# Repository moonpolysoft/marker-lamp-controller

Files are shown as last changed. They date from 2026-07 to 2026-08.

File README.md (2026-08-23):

# F-150 Lightning Auxiliary Marker-Lamp Controller

An open-hardware controller that makes aftermarket amber grille marker lamps
follow the factory parking lamps on a 2023 Ford F-150 Lightning—without using
the CAN bus or trailer-lighting outputs.

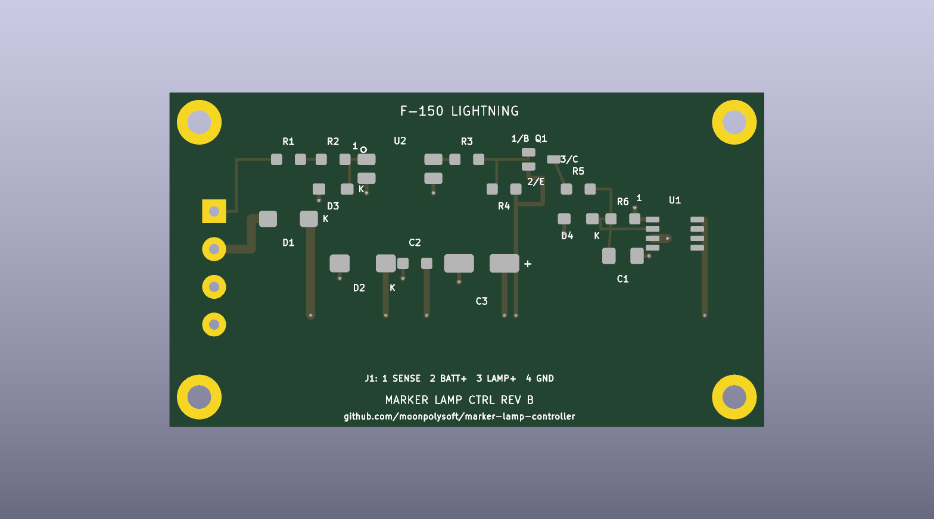
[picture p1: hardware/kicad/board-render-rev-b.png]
Revision B controller PCB


## Status

- Revision A was assembled, bench tested, and verified in the vehicle.
- The selected driver-side rear parking-lamp signal provides the desired lamp
  behavior. No front-lamp or CAN connection is required.
- Revision B corrects the three assembly issues found on Revision A. A
  Revision B board has been assembled, bench tested, installed, and verified
  working in the vehicle.
- The current enclosure prototype has been printed and its mechanical fit is
  confirmed, including the revised connector opening, boss clearances, and
  recessed lid screws.

This remains a hobbyist engineering prototype, not a Ford-approved accessory
or a safety-certified automotive product. Read [Safety](#safety) before
building or installing it.

## Finished build

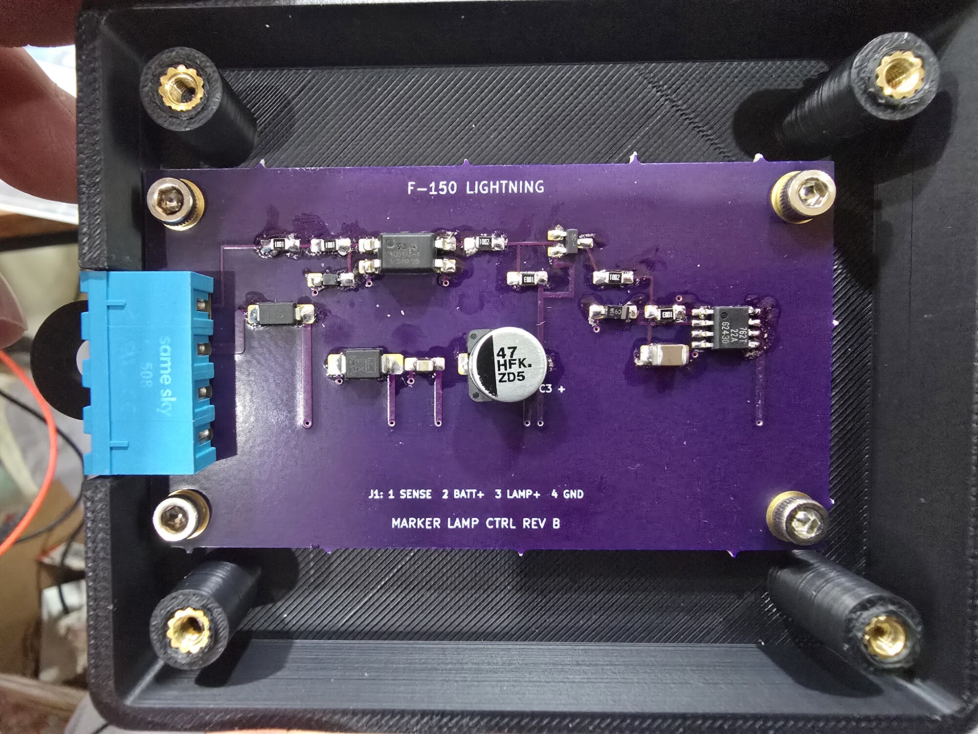
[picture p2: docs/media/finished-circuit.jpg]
Assembled Revision B controller installed in the printed enclosure


The completed controller follows the selected factory parking-lamp signal and
switches the three aftermarket amber grille lamps as intended.

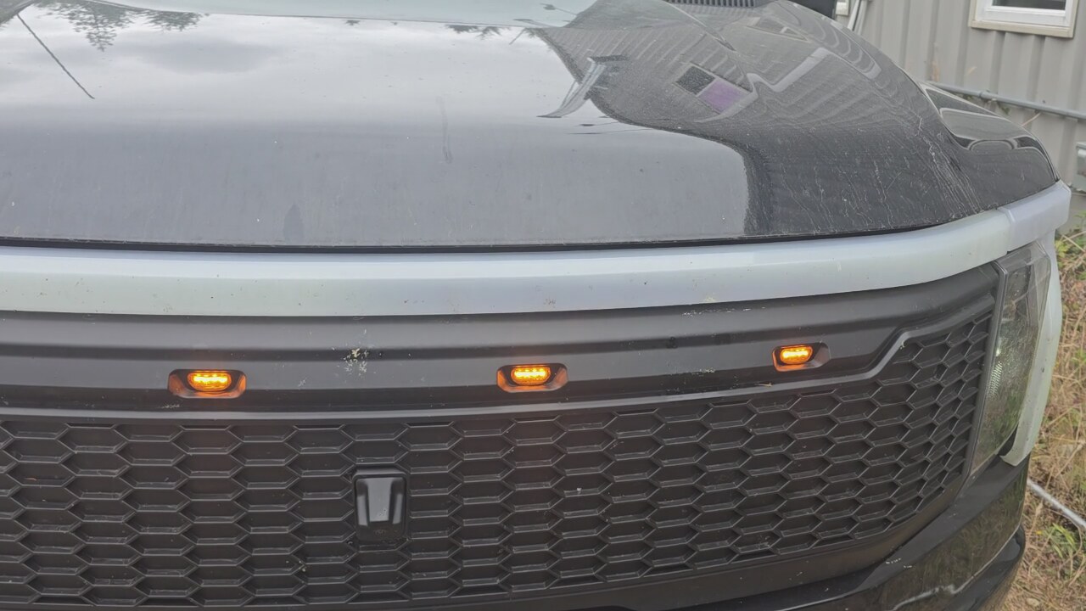
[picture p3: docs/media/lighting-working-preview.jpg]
Video preview showing the auxiliary amber grille lamps illuminated


[Play or download the installation demonstration (MP4, H.264/AAC)](docs/media/lighting-working.mp4)

## What it does

The controller senses the factory rear parking-lamp output through an
optocoupler and drives the aftermarket LEDs from a separate fused 12 V supply
using a protected high-side switch. The factory lamp circuit supplies only the
sense current; it does not power the added lamps.

```text
Factory rear parking-lamp output ── isolated sense/filter ──┐
                                                            │
Fused 12 V supply ── protected high-side switch ── marker lamps
Vehicle ground ─────────────────────────────────── marker return
```

The tested aftermarket lamp assembly draws approximately 0.25 A with the
vehicle low-voltage system energized. The observed sense signal reads roughly
6 V with the truck off and 8 V with it on when measured by a multimeter,
consistent with a pulse-width-modulated automotive lamp output.

## Repository contents

| Path | Contents |
|---|---|
| [`hardware/kicad/`](hardware/kicad/) | KiCad boards, deterministic PCB generator, BOM, DRC reports, Gerbers, drill files, and OSH Park upload archives |
| [`hardware/controller-design.md`](hardware/controller-design.md) | Circuit architecture, component rationale, and validation notes |
| [`enclosure/`](enclosure/) | Parametric OpenSCAD enclosure source and printable STL exports |
| [`docs/rear-parking-wire-test.md`](docs/rear-parking-wire-test.md) | Procedure used to identify and verify the vehicle signal |
| [`docs/media/`](docs/media/) | Finished controller photo and in-vehicle demonstration video |

Revision B is the current PCB. Revision A files remain available as design
history but include known assembly defects; do not order Revision A.

## Building the board

The easiest fabrication input is:

[`hardware/kicad/fabrication-rev-b/marker-lamp-controller-rev-b-oshpark.zip`](hardware/kicad/fabrication-rev-b/marker-lamp-controller-rev-b-oshpark.zip)

The board is a two-layer, 80 × 45 mm design made for OSH Park's standard
two-layer service. Review the current [`BOM.csv`](hardware/kicad/BOM.csv),
because distributor stock and manufacturer lifecycle status change over time.
Connector pinout, board specifications, regeneration instructions, and known
Revision A defects are documented in the
[`hardware/kicad/README.md`](hardware/kicad/README.md).

To regenerate the PCB source with KiCad 10's Python environment:

```sh
python3 hardware/kicad/generate_pcb.py
```

The generator and
[`circuit-netlist.md`](hardware/kicad/circuit-netlist.md) are the authoritative
circuit sources. This project currently does not contain a conventional KiCad
schematic.

## Printing the enclosure

Open [`controller_enclosure.scad`](enclosure/controller_enclosure.scad) in
OpenSCAD and select `base` or `lid`, or print the supplied STL files. See the
[`enclosure/README.md`](enclosure/README.md) for hardware dimensions, material
recommendations, and print settings. The lid should be printed with a 5 mm
brim.

## Installation summary

J1 uses a Same Sky `TBP01R1-508-04BE` board header with a
`TBP01P1-508-04BE` wire-side plug:

| Pin | Signal | Connection |
|---:|---|---|
| 1 | `SENSE` | Verified parking-lamp signal tap |
| 2 | `BATT+` | Separately fused 12 V supply |
| 3 | `LAMP+` | Switched positive output to marker LEDs |
| 4 | `GND` | Chassis ground and lamp return |

Place the branch fuse near the power source. The design documentation calls
for a 2 A fuse and 18 AWG automotive primary wire for the tested 0.25 A load.
Confirm wiring, fuse size, polarity, and connector numbering against your own
vehicle and hardware; model-year and trim wiring can differ.

## Safety

Automotive electrical systems can produce load-dump, inductive, reverse-
polarity, and electrostatic transients. A wiring fault can damage vehicle
modules or start a fire. Disconnect the low-voltage battery as directed by the
vehicle service procedure before permanent wiring, protect added conductors
with an appropriately placed fuse, use automotive-rated wire and abrasion
protection, and secure the assembly away from heat, water, sharp edges, and
moving parts.

Do not treat a zero-error DRC result as validation of electrical safety. Test
every assembled board with a current-limited bench supply before vehicle use.
You build and install this project at your own risk.

Ford and F-150 Lightning are trademarks of their respective owner. This
project is independent and is not affiliated with or endorsed by Ford Motor
Company.

## Contributing

Bug reports, measurements, documentation corrections, and design improvements
are welcome. See [`CONTRIBUTING.md`](CONTRIBUTING.md) before submitting a
change. In particular, identify the PCB revision and vehicle model year/trim
when reporting electrical behavior.

## License

This project is open hardware licensed under the
[CERN Open Hardware Licence Version 2—Strongly Reciprocal](LICENSE), SPDX
identifier `CERN-OHL-S-2.0`.

You may use, study, modify, manufacture, and distribute the design subject to
the licence terms. The strongly reciprocal variant was selected so that
distributed modified designs and products remain accompanied by corresponding
design source. The licence includes warranty and liability disclaimers; it is
not a certification of fitness for automotive use.

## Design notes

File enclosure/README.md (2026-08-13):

# Controller Enclosure Concept

`controller_enclosure.scad` is a parametric enclosure consisting of a base and
lid sized for the current Revision B controller PCB. Its fit has been confirmed
with a printed prototype.

Default external dimensions are approximately 96 × 80 × 23.2 mm, excluding
mounting tabs. The lid roof is 4.2 mm thick so recessed screw heads retain a
1.2 mm supporting floor.

The left wall has a support-free, top-open notch sized to admit the Same Sky
`TBP01P1-508-04BE` four-position mating plug from outside. The lid lip is
relieved over the same opening. The nominal 22.5 mm opening width provides
approximately 2.2 mm total clearance around the plug's 20.32 mm length.

The PCB is shifted toward the J1 wall, leaving 0.5 mm nominal clearance
between that PCB edge and the inside wall. The wider enclosure provides more
than 2 mm nominal radial clearance between the populated PCB corners and the
nearest lid bosses. The lid bosses are also inset far enough to leave 1.6 mm
nominal clearance from the inside edge of the lid lip.

The base notch and lid relief deliberately use mirrored source coordinates:
the lid is printed exterior-face down and flipped for assembly. This makes the
two openings align when the enclosure is closed.

Revision B moves J1 by 7 mm along the PCB edge to clear its mounting hole.
The enclosure opening center follows the new connector position.

The base is 19 mm tall, including its 3 mm floor. The solid wall beneath the
J1 notch is 9.5 mm tall.

## Generate models

Open the file in OpenSCAD and change `part`:

```scad
part = "base";
part = "lid";
part = "assembly";
```

Export the base and lid separately as STL.

Command-line examples:

```sh
openscad -D 'part="base"' -o controller_base.stl controller_enclosure.scad
openscad -D 'part="lid"' -o controller_lid.stl controller_enclosure.scad
```

## Printing assumptions

- Material: ASA preferred for heat and UV resistance; PETG is suitable for
  an interior dry prototype. PLA is not recommended in a vehicle.
- Layer height: 0.20 mm
- Walls: at least 4 perimeters
- Top/bottom layers: at least 5
- Infill: 30% or greater around mounting tabs
- Print both pieces with their large flat exterior faces on the build plate.
- Lid: use a 5 mm brim to prevent the edges from peeling up from the print
  bed.

## Hardware assumptions

- Lid: four M3 machine screws into heat-set inserts.
- Lid screw recesses: 5.8 mm diameter × 3.0 mm deep, sized for nominal
  5.5 mm-diameter, 3.0 mm-tall heads. Verify the actual screw heads before
  the final print.
- Insert pocket: 4.2 mm diameter × 5.5 mm deep; adjust these two parameters to
  the actual insert manufacturer's recommended hole dimensions.
- Lid insert bosses finish 0.75 mm below the base rim to keep heat-set-insert
  squeeze-out from interfering with lid fit.
- PCB: four M3 screws driven into 2.7 mm pilot holes in printed standoffs.
- PCB mounting pattern: 72 × 37 mm.
- The two PCB standoffs opposite J1 include a 0.5 mm outward print-fit
  adjustment, producing 72.5 mm modeled spacing in that axis.
- No environmental gasket is required for the dry installation location; the
  existing shallow channel may be left unused.

The current lid uses screws, not printed snap fits. The model includes an
O-ring/gasket channel concept, but sealing has not been validated. Use sealed
cable glands or sealed bulkhead connectors for an exterior/underbody mounting
location.

## Checks before vehicle installation

- Confirm the selected heat-set insert diameter and length before printing.
- Confirm that the installed lid screws remain long enough for full insert
  engagement with the recessed 4.2 mm lid roof.
- Verify that the populated PCB, Q1 rework, C3, header, and mating plug clear
  the lid and screw bosses.
- Verify that the connector can be inserted and removed with the lid fitted.
- Confirm the enclosure mounting-tab hole locations against the vehicle.

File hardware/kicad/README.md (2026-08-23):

# Fabrication Design

This directory contains Revision A and Revision B of the two-layer
marker-lamp controller. Revision B is the current fabrication design.

## Files

- `marker-lamp-controller.kicad_pcb` — generated KiCad 10 PCB.
- `marker-lamp-controller-rev-b.kicad_pcb` — corrected Revision B PCB.
- `generate_pcb.py` — deterministic PCB generator using KiCad's `pcbnew`
  Python module.
- `circuit-netlist.md` — readable authoritative circuit connectivity.
- `revision-b-notes.md` — corrections found while assembling Revision A that
  must be incorporated before the next board order.
- `BOM.csv` — orderable manufacturer and DigiKey part numbers.
- `drc-report.txt` — KiCad board DRC result.
- `fabrication/` — OSH Park Gerbers and separate plated/non-plated drills.
- `fabrication-rev-b/` — Revision B OSH Park Gerbers, drills, and upload ZIP.
- `board-render.png` — top-side board preview (custom hand-solder footprints
  do not carry 3D body models).
- `board-render-rev-b.png` — Revision B top-side board preview.

Revision B includes top-side reference designators, diode cathode markings,
C3 polarity, U1/U2 pin-1 cues, Q1 lead labels, the complete J1 pinout, and the
project source URL to support hand assembly and design-source identification.

The PCB generator and `circuit-netlist.md` are authoritative for Revision B.

## Connector

Board header:

- Same Sky `TBP01R1-508-04BE`

Mating pluggable terminal connector:

- Same Sky `TBP01P1-508-04BE`

Pinout:

1. `SENSE` — driver-side rear parking output, C4483 cavity 10,
   violet/green.
2. `BATT+` — separately fused 12 V feed; use a 2 A fuse.
3. `LAMP+` — switched positive output to the 0.25 A grille LEDs.
4. `GND` — chassis ground and grille LED return.

## Board construction

- 80 × 45 mm
- Two copper layers
- 1 oz copper
- Minimum designed trace/space: 0.20 mm / 0.20 mm
- Signal traces: 0.35–0.60 mm
- Power/load traces: 1.2 mm
- Vias: 0.8 mm finished pad, 0.4 mm drill
- Four 3.2 mm non-plated mounting holes
- Mounting-hole centers: 72 × 37 mm
- Components on the top side

These values exceed the OSH Park two-layer minima of 0.1524 mm
trace/spacing, 0.127 mm annular ring, and 0.254 mm minimum drill.

## DigiKey availability review

The BOM was checked against DigiKey stock on 2026-07-24. Stock changes
continuously, so verify it again before ordering.

- BSP762TXUMA1: stocked, cut tape available.
- VO617A-4X017T: stocked, cut tape available.
- TBP01R1-508-04BE header: stocked.
- TBP01P1-508-04BE mating plug: stocked.
- STPS2H100A and SMBJ22A: stocked, cut tape available.
- SBC807-40LT1G: stocked, automotive-qualified.
- 1N4148WS: stocked alternate selected.
- BZT52-C5V1-QX: stocked, automotive-qualified.
- CGA6P1X7R1E106K250AC: stocked, automotive-qualified.
- C0805C104K5RAC7210: stocked, active replacement for an obsolete Murata
  bypass capacitor considered during selection.
- EEE-FK1H470P and all three Yageo resistor values: stocked.

## Regenerate

```sh
python3 generate_pcb.py
```

Run from this directory or from the project root using the full relative path.

Generate the top-side repository preview from the project root with:

```sh
kicad-cli pcb render --side top --quality basic --background opaque \
  --width 1600 --height 900 --zoom 1.15 \
  -o hardware/kicad/board-render-rev-b.png \
  hardware/kicad/marker-lamp-controller-rev-b.kicad_pcb
```

The custom hand-solder footprints do not include 3D component-body models, so
the render intentionally shows the bare board, pads, and assembly silkscreen.

## Status

An assembled Revision B board has been bench tested, installed, and verified
working in the vehicle with the intended 0.25 A marker-lamp load. It remains an
engineering prototype; independent builders should bench test every assembly
and characterize turn-on/off behavior, reverse polarity, output short
protection, thermal behavior, and vehicle sleep current before permanent
installation.

KiCad 10 DRC reports zero violations, zero unconnected pads, and zero footprint
errors for Revision B. This verifies the artwork rules and connectivity, not
vehicle behavior.

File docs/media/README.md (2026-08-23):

# Project Media

- `finished-circuit.jpg` — assembled Revision B controller in the printed
  enclosure; web-sized JPEG with camera metadata removed.
- `lighting-working-preview.jpg` — still image used as the clickable video
  preview in the main README.
- `lighting-working.mp4` — 15.7-second in-vehicle demonstration, transcoded to
  1280 × 720 H.264 video with AAC audio for broad browser compatibility.

The media documents one functioning build; it does not replace the electrical
and installation validation required for another vehicle or assembly.

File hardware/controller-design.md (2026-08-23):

# Auxiliary Marker-Lamp Controller

Status: Revision B assembled, bench tested, installed, and verified working in
the vehicle.

## Confirmed measurements

- C4483 cavity 10, violet/green, follows the desired parking-lamp behavior.
- Multimeter indication with parking lamps active:
  - approximately 6 V with the truck off;
  - approximately 8 V with the truck on.
- Total aftermarket marker-lamp current: 0.25 A while supplied by the truck's
  energized accessory circuit.
- The input waveform has not yet been characterized with an oscilloscope. The
  assembled circuit nevertheless responds correctly to the selected signal in
  the vehicle.

The most likely explanation for the reduced multimeter readings is
battery-amplitude PWM. The input circuit must therefore accumulate valid PWM
pulses while rejecting isolated diagnostic pulses.

## Requirements

- Detect the factory rear parking-lamp output without CAN or trailer wiring.
- Add no more than approximately 6 mA peak to the BCM parking-lamp output.
- Power the aftermarket lamps from a separate fused 12 V feed.
- Prevent off-state diagnostic pulses from flashing the aftermarket lamps.
- Default to auxiliary lamps off after an open circuit or loss of controller
  power.
- Tolerate reverse polarity and common automotive electrical transients.

## Proposed architecture

```text
 C4483-10
 VT-GN
    |
 PWM-compatible optocoupler input
    |
 asymmetric RC pulse filter
    |
 automotive smart high-side switch

 Separate fused 12 V ---- smart switch ---- amber marker lamps
 Vehicle ground ----------------------------- marker-lamp ground
```

The optocoupler separates the BCM sense circuit from the load controller. A
protected automotive high-side switch supplies the 0.25 A lamp load and
eliminates relay-coil power, audible clicking, and contact wear.

## Candidate circuit

### Factory-lamp sense input

| Ref | Candidate value/part | Purpose |
|---|---|---|
| D3 | 1N4148WS, anti-parallel with optocoupler LED | Reverse-voltage protection |
| R1, R2 | 1.0 kΩ, 0.25 W each, series | Set LED current and share dissipation |
| U2 | VO617A-4X017T | Isolated detection with specified high CTR |

If the suspected PWM waveform rises to 14.8 V, two 1.0 kΩ resistors produce
approximately:

```text
(14.8 V - 1.2 V) / 2.0 kΩ = 6.8 mA peak
```

If the signal is actually steady DC, input current is approximately 2.4 mA at
6 V and 3.4 mA at 8 V. These values provide substantially more optocoupler
margin than the original 5.4 kΩ proposal while remaining a small additional
BCM load. Final resistor values remain subject to waveform and temperature
testing.

Do not add a large capacitor directly to the BCM output. PWM accumulation and
diagnostic-pulse rejection are performed on the isolated, low-voltage side.

### Isolated pulse filter and high-side-switch control

| Ref | Candidate value/part | Purpose |
|---|---|---|
| Q1 | SBC807-40LT1G | PNP level shifter driven by the optocoupler |
| R3 | 10 kΩ | Limits optocoupler/base current |
| R4 | 100 kΩ | Holds Q1 off without a sense signal |
| R5 | 10 kΩ | Charges the filtered control node |
| R6 | 100 kΩ | Discharges the filtered node after pulses stop |
| C1 | 10 µF | Accumulates parking-lamp PWM pulses |
| D4 | BZT52-C5V1-QX | Clamps the switch input near 5.1 V |
| U1 | BSP762TXUMA1 | Protected automotive high-side lamp switch in SO-8 |

The optocoupler turns on Q1 during each parking-lamp pulse. Q1 charges C1
through R5; R6 discharges it when pulses stop. D4 limits the resulting control
voltage for U1. The nominal charge time constant is 0.10 seconds and the
nominal discharge time constant is 1.0 second, providing persistence through
normal lamp PWM without placing a capacitor on the BCM output.

The timing values remain subject to characterization. Real switching behavior depends on PWM
frequency and duty cycle, U3 thresholds, optocoupler current-transfer ratio,
temperature, and capacitor tolerance. Select R3, R4, and C1 after a scope
capture or by conservative pulse-generator bench testing. Tie unused
Schmitt-trigger inputs to a defined logic level.

The BSP762TXUMA1 is an automotive smart high-side switch in a hand-solderable SO-8
package with short-circuit, overload, overvoltage, and thermal protection. At
0.25 A and its typical 70 mΩ on-resistance, nominal conduction loss is:

```text
P = I²R = 0.25² × 0.07 = 0.0044 W
```

Its protection threshold is fixed internally. The external 2 A branch fuse
protects the feed wiring and provides a second level of fault protection.

### Lamp-power path

```text
12 V source -- F2 -- U4 supply
U4 output -- auxiliary marker lamp positive
auxiliary marker lamp negative -- chassis ground
```

F2 must be located close to the power source. Use a 2 A automotive branch fuse
with 18 AWG automotive primary wire from the fuse-box tap to the controller.
The 2 A fuse provides ample margin over the measured 0.25 A operating current,
while U1 provides downstream overload and short-circuit
protection:

```text
1.25 × 0.25 A = 0.3125 A
```

The fuse must protect every conductor between the fuse-box tap and U1. The
smaller grille pigtail also benefits from U1's fixed internal current limiting.
A 5 A
upstream fuse is also compatible with 18 AWG feed wiring, but 2 A provides
better protection and adequate operating margin for this load.

## Installation interfaces

Provisional four-circuit arrangement:

1. `SENSE` — fused high-impedance connection to C4483-10, violet/green.
2. `BATT+` — separately fused controller/load supply.
3. `GND` — chassis ground.
4. `LAMP+` — switched output to the marker lamps.

A fifth terminal can provide a dedicated lamp return if relying on local
chassis grounding is undesirable.

Use sealed automotive connectors, strain relief, abrasion-resistant loom, and
drip loops. The enclosure should not be the primary environmental seal for
unsealed wire penetrations.

## Bench validation before vehicle installation

1. Sweep the sense input from 0 to 16 V and record output thresholds.
2. Apply short 12–15 V pulses and verify pulses shorter than the measured BCM
   diagnostic pulse do not enable the output.
3. Hold the input at 14.8 V for at least one hour and check component
   temperatures.
4. Test input reverse polarity through a current-limited supply.
5. Test power interruption and brownout; output oscillation is unacceptable.
6. Test at the maximum expected lamp current with the actual harness and fuse.
7. Confirm the output switches off when the sense conductor is disconnected.

## Future characterization

- Actual parking-lamp PWM amplitude, frequency, and duty cycle
- Measured off-state diagnostic-pulse width and interval, if any
- Turn-on and turn-off thresholds across automotive temperature extremes
- Vehicle sleep-current contribution over an extended parked interval
- Transient-immunity testing beyond normal bench and in-vehicle operation

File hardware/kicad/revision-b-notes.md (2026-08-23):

# Revision B (V2) Notes

These items were discovered while assembling and bench-testing Revision A.
They are implemented in the generated Revision B PCB. Keep this file as the
design rationale and fabrication checklist.

## 1. Correct the Q1 footprint pin mapping

Revision A swaps Q1 pins 1 and 2 at the physical SOT-23 pads. The specified
onsemi `SBC807-40LT1G` uses:

- Pin 1: base
- Pin 2: emitter
- Pin 3: collector

With the SOT-23 mounted component-side up and its single lead on the right,
the physical leads are:

- Upper-left: pin 1, base -- connect to `QBASE`
- Lower-left: pin 2, emitter -- connect to `VPWR`
- Right: pin 3, collector -- connect to `QCOL`

Revision A instead connects the upper-left pad to `VPWR` and the lower-left
pad to `QBASE`. The assembled prototype required both left leads to be lifted
and cross-wired. Revision B connects upper-left pin 1 to `QBASE`, lower-left
pin 2 to `VPWR`, and right-side pin 3 to `QCOL`.

## 2. Resolve the J1/mounting-hole interference

J1 mechanically overlaps the upper-left mounting-hole area. Reposition J1,
the mounting hole, or both so the complete connector body, mating-plug access,
wire-entry space, and tool-access envelope clear the mounting hardware.

Revision B moves J1 7 mm toward the lower-left mounting hole. Its body now
occupies Y=14.2–35.1 mm, between the two left mounting holes at Y=5 and
Y=42 mm. The matching enclosure opening moves by the same 7 mm.

## 3. Enlarge the C3 footprint

The Revision A C3 footprint is too narrow for the actual Panasonic
`EEE-FK1H470P` capacitor. Revision B uses the standard 8 × 6.2 mm SMD-can
geometry: 6.1 mm pad-center spacing, 4.0 × 2.5 mm pads, and an 8.3 × 8.3 mm
body envelope.

Before releasing Revision B, measure the received component and verify:

- Pad width, length, and center spacing
- 8 mm-class can body clearance
- Polarity marking and silkscreen visibility
- Hand-soldering access around both terminals
- Clearance to adjacent components and traces

## Revision B release record

Revision B implements all three corrections and passed a fresh KiCad DRC with
no violations or unconnected pads before submission to OSH Park. The enclosure
was updated for the relocated J1 and confirmed by prototype printing. A
fabricated Revision B board has since been assembled, bench tested, installed,
and verified working in the vehicle.

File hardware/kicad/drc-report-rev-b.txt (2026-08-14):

** Drc report for marker-lamp-controller-rev-b.kicad_pcb **
** Created on 2026-08-13T19:37:50 **
** Report includes: Errors, Warnings **

** Found 0 DRC violations **

** Found 0 unconnected pads **

** Found 0 Footprint errors **

** Ignored checks **
    - Footprint has no courtyard defined
    - Track endpoint not centered on via
    - Tuning profile track geometries
    - Footprint doesn't match symbol's footprint filters
    - Footprint component type doesn't match footprint pads

** End of Report **

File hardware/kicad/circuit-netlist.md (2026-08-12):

# Revision B Circuit Connectivity

This is the authoritative human-readable netlist for the PCB. Pin numbers
refer to component package pins, not schematic-symbol ordering.

| Net | Connections |
|---|---|
| `SENSE` | J1-1, R1-1 |
| `SENSE_LED` | R1-2, R2-1 |
| `OPTO_A` | R2-2, U2-1, D3 cathode |
| `GND` | J1-4, U2-2, U2-3, D3 anode, D2 anode, C2-2, C3-2, U1-1, R6-2, C1-2, D4 anode |
| `VPRE` (`BATT_RAW`) | J1-2, D1 anode |
| `VPWR` | D1 cathode, D2 cathode, C2-1, C3-1, R4-1, Q1-2 emitter, U1 pins 5–8 |
| `QBASE` | U2-4 collector, R3-1 |
| `QBASE_BIAS` | R3-2, R4-2, Q1-1 base |
| `QCOL` | Q1-3 collector, R5-1 |
| `CTRL` | R5-2, R6-1, C1-1, D4 cathode, U1-2 |
| `LAMP_OUT` | U1-3, J1-3 |
| `NC` | U1-4 only |

## Package pin checks

- U1 `BSP762TXUMA1`: 1 GND, 2 IN, 3 OUT, 4 NC, 5–8 Vbb.
- U2 `VO617A-4X017T`: 1 LED anode, 2 LED cathode, 3 transistor emitter,
  4 transistor collector.
- Q1 `SBC807-40LT1G`: 1 base, 2 emitter, 3 collector.
- C3 `EEE-FK1H470P`: pin 1/right pad is positive (`VPWR`); pin 2/left
  pad is negative (`GND`).
- D1 is the series reverse-polarity diode.
- D2 is the supply TVS.
- D3 is antiparallel to the optocoupler LED.
- D4 is the 5.1 V control-node clamp.

## Installation connector

1. `SENSE` — C4483 cavity 10, violet/green.
2. `BATT_RAW` — 12 V feed with an external 2 A fuse at the source.
3. `LAMP_OUT` — positive feed to the grille lamps.
4. `GND` — chassis ground and lamp return.

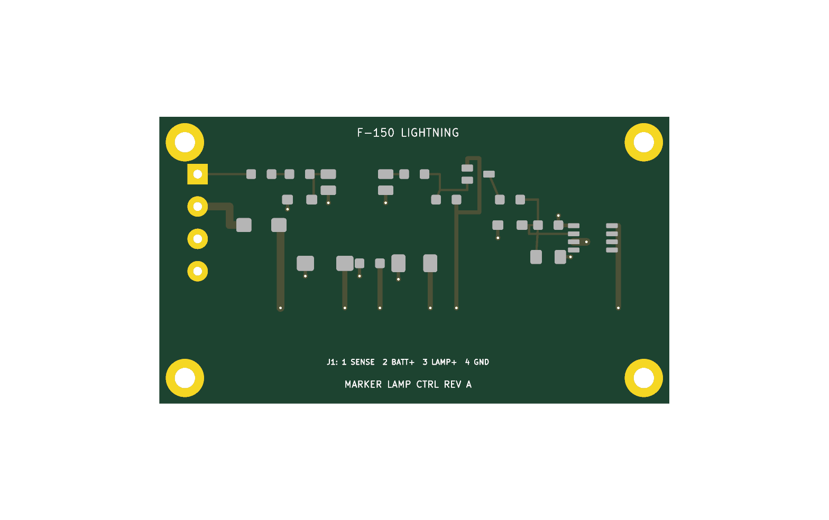
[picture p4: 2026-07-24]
hardware/kicad/board-render.png

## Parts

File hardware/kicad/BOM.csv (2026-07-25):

Reference | Quantity | Value | Manufacturer | Manufacturer Part Number | Package | Notes
J1 | 1 | 4-position pluggable board header | Same Sky | TBP01R1-508-04BE | THT 5.08 mm | DigiKey 102-6408-ND
J1M | 1 | 4-position wire-side pluggable terminal block | Same Sky | TBP01P1-508-04BE | 5.08 mm plug | DigiKey 102-6392-ND; screw-clamp wire termination; no separate contacts required
U1 | 1 | Smart high-side switch | Infineon | BSP762TXUMA1 | PG-DSO-8 | DigiKey BSP762TXUMA1CT-ND; AEC qualified; active
U2 | 1 | Optocoupler | Vishay | VO617A-4X017T | DIP-4 SMD | CTR rank 4; gull-wing leads
Q1 | 1 | PNP transistor | onsemi | SBC807-40LT1G | SOT-23 | DigiKey SBC807-40LT1GOSCT-ND; AEC-Q101
D1 | 1 | 100 V 2 A Schottky | STMicroelectronics | STPS2H100A | SMA | Series reverse-polarity protection
D2 | 1 | 22 V TVS | Littelfuse | SMBJ22A | SMB | Unidirectional transient clamp
D3 | 1 | Small-signal diode | SMC Diode Solutions | 1N4148WS | SOD-323 | DigiKey 1655-1N4148WSCT-ND; optocoupler LED reverse protection
D4 | 1 | 5.1 V Zener | Nexperia | BZT52-C5V1-QX | SOD-123 | DigiKey 1727-BZT52-C5V1-QXCT-ND; AEC-Q101; control-node clamp
R1 R2 | 2 | 1k 1% 0.125 W | Yageo | RC0805FR-071KL | 0805 | DigiKey 311-1.00KCRCT-ND; sense current limit; series pair
R3 R5 | 2 | 10k 1% | Yageo | RC0805FR-0710KL | 0805
R4 R6 | 2 | 100k 1% | Yageo | RC0805FR-07100KL | 0805
C1 | 1 | 10 uF 25 V X7R AEC-Q200 | TDK | CGA6P1X7R1E106K250AC | 1210 | DigiKey 445-7000-1-ND; PWM accumulator
C2 | 1 | 100 nF 50 V X7R | KEMET | C0805C104K5RAC7210 | 0805 | DigiKey 399-C0805C104K5RAC7210CT-ND; VPWR bypass
C3 | 1 | 47 uF 50 V | Panasonic | EEE-FK1H470P | 8 mm SMD electrolytic | VPWR bulk
H1 H2 H3 H4 | 4 | M3 mounting hole |  |  | 3.2 mm NPTH

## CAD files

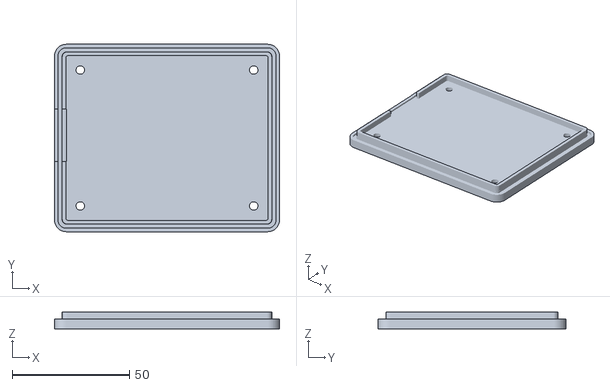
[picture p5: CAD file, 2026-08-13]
enclosure/controller_lid_prototype.stl
96.0 x 80.0 x 7.20

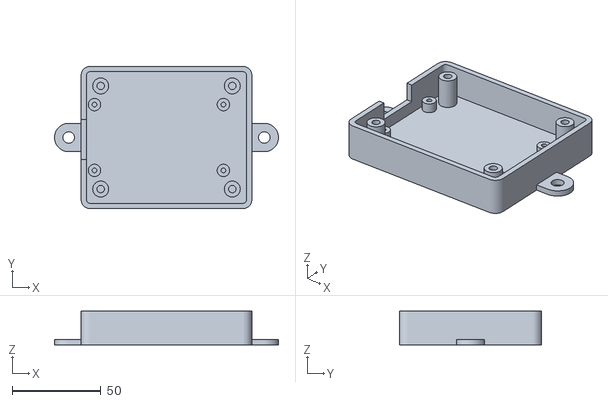
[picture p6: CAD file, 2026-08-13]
enclosure/controller_base_prototype.stl
126.0 x 80.0 x 19.0

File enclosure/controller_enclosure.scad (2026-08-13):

/*
  Preliminary auxiliary marker-lamp controller enclosure.
  Units: millimeters.

  Export base and lid separately by changing `part`.
*/

part = "assembly"; // "base", "lid", or "assembly"

inside_length = 90;
inside_width = 74;
inside_height = 16;
wall = 3;
floor_thickness = 3;
// A 4.2 mm roof leaves 1.2 mm of material beneath the 3 mm-deep lid-screw
// counterbores.  The previous 3 mm roof was too thin to recess the heads.
lid_thickness = 4.2;
corner_radius = 5;
lid_clearance = 0.30;

lid_screw_clearance_diameter = 3.6;
lid_screw_head_diameter = 5.8;
lid_screw_head_recess_depth = 3.0;
lid_insert_hole_diameter = 4.2;
lid_insert_depth = 5.5;
screw_boss_diameter = 9;
screw_edge_offset = 11;
// Keep heat-set-insert flare/squeeze-out below the base rim so it cannot
// interfere with the underside of the lid.
screw_boss_top_setback = 0.75;

pcb_length = 80;
pcb_width = 45;
pcb_hole_spacing_x = 72;
pcb_hole_spacing_y = 37;
pcb_standoff_height = 5;
pcb_screw_diameter = 2.7;
pcb_shift_x = -4.5;
pcb_far_standoff_adjust_x = 0.5;

// Opening for the 4-position TBP01P1-508 mating plug.  The plug is
// 20.32 mm long and approximately 15 x 18 mm in cross-section.  A top-open
// notch avoids an unsupported bridge and permits insertion from outside.
j1_center_from_pcb_edge = 23.62;
j1_opening_width = 22.5;
j1_opening_bottom = 9.5;

mount_tab_length = 14;
mount_tab_width = 16;
mount_hole_diameter = 6.5;

gasket_width = 1.8;
gasket_depth = 1.0;

outer_length = inside_length + 2 * wall;
outer_width = inside_width + 2 * wall;
base_height = inside_height + floor_thickness;
pcb_edge_y = (outer_width - pcb_width) / 2;
j1_lid_relief_center_y = pcb_edge_y + j1_center_from_pcb_edge;
// The lid is printed exterior-face down and flipped about Y for assembly.
// Its printable relief therefore remains mirrored relative to the base notch.
j1_base_opening_center_y = outer_width - j1_lid_relief_center_y;

$fn = 48;

module rounded_box(size, radius) {
    hull() {
        for (x = [radius, size[0] - radius])
            for (y = [radius, size[1] - radius])
                translate([x, y, 0])
                    cylinder(r = radius, h = size[2]);
    }
}

module mounting_tab(y_center) {
    translate([-mount_tab_length, y_center - mount_tab_width / 2, 0])
        difference() {
            hull() {
                translate([mount_tab_length, 0, 0])
                    cube([1, mount_tab_width, floor_thickness]);
                translate([mount_tab_length / 2, mount_tab_width / 2, 0])
                    cylinder(d = mount_tab_width, h = floor_thickness);
            }
            translate([mount_tab_length / 2, mount_tab_width / 2, -0.1])
                cylinder(d = mount_hole_diameter,
                         h = floor_thickness + 0.2);
        }
}

module enclosure_screw_boss(x, y) {
    translate([x, y, floor_thickness - 0.1])
        difference() {
            cylinder(d = screw_boss_diameter,
                     h = inside_height + 0.1 - screw_boss_top_setback);
            // Blind pocket entered from the top for a common M3 heat-set
            // insert.  Tune diameter/depth to the inserts actually used.
            translate([0, 0,
                       inside_height - screw_boss_top_setback
                       - lid_insert_depth])
                cylinder(d = lid_insert_hole_diameter,
                         h = lid_insert_depth + 0.3);
        }
}

module pcb_standoff(x, y) {
    translate([x, y, floor_thickness - 0.1])
        difference() {
            cylinder(d = 7, h = pcb_standoff_height + 0.1);
            translate([0, 0, -0.1])
                cylinder(d = pcb_screw_diameter,
                         h = pcb_standoff_height + 0.4);
        }
}

module base() {
    difference() {
        union() {
            difference() {
                rounded_box(
                    [outer_length, outer_width, base_height],
                    corner_radius
                );
                translate([wall, wall, floor_thickness])
                    rounded_box(
                        [inside_length, inside_width,
                         inside_height + 0.1],
                        max(corner_radius - wall, 1)
                    );
            }
            mounting_tab(outer_width / 2);
            translate([outer_length, outer_width, 0])
                rotate([0, 0, 180])
                    mounting_tab(outer_width / 2);

            for (x = [screw_edge_offset,
                      outer_length - screw_edge_offset])
                for (y = [screw_edge_offset,
                          outer_width - screw_edge_offset])
                    enclosure_screw_boss(x, y);

            for (x = [(outer_length - pcb_hole_spacing_x) / 2
                      + pcb_shift_x,
                      (outer_length + pcb_hole_spacing_x) / 2
                      + pcb_shift_x + pcb_far_standoff_adjust_x])
                for (y = [(outer_width - pcb_hole_spacing_y) / 2,
                          (outer_width + pcb_hole_spacing_y) / 2])
                    pcb_standoff(x, y);
        }

        // Direct-access notch for inserting the wire-side J1 plug through
        // the left wall.  It remains open at the top for support-free print.
        translate([-0.1,
                   j1_base_opening_center_y - j1_opening_width / 2,
                   j1_opening_bottom])
            cube([wall + 0.2,
                  j1_opening_width,
                  base_height - j1_opening_bottom + 0.2]);
    }
}

module lid() {
    lip_height = 3;
    lip_wall = 1.6;

    difference() {
        union() {
            rounded_box(
                [outer_length, outer_width, lid_thickness],
                corner_radius
            );
            translate([wall + lid_clearance,
                       wall + lid_clearance,
                       lid_thickness - 0.1])
                difference() {
                    rounded_box(
                        [inside_length - 2 * lid_clearance,
                         inside_width - 2 * lid_clearance,
                         lip_height + 0.1],
                        max(corner_radius - wall, 1)
                    );
                    translate([lip_wall, lip_wall, -0.1])
                        rounded_box(
                            [inside_length - 2 * lid_clearance
                             - 2 * lip_wall,
                             inside_width - 2 * lid_clearance
                             - 2 * lip_wall,
                             lip_height + 0.2],
                            max(corner_radius - wall - lip_wall, 0.8)
                        );
                }
        }

        for (x = [screw_edge_offset,
                  outer_length - screw_edge_offset])
            for (y = [screw_edge_offset,
                      outer_width - screw_edge_offset])
                union() {
                    // Through clearance for the M3 screw shank.
                    translate([x, y, -0.1])
                        cylinder(d = lid_screw_clearance_diameter,
                                 h = lid_thickness + lip_height + 0.2);
                    // Flat-bottom recess entered from the exterior face.
                    // 0.3 mm radial clearance accommodates a nominal
                    // 5.5 mm-diameter screw head and print tolerance.
                    translate([x, y, -0.1])
                        cylinder(d = lid_screw_head_diameter,
                                 h = lid_screw_head_recess_depth + 0.1);
                }

        // Remove the lid lip above J1 while retaining the solid lid roof.
        translate([-0.1,
                   j1_lid_relief_center_y - j1_opening_width / 2,
                   lid_thickness - 0.15])
            cube([wall + lid_clearance + lip_wall + 0.3,
                  j1_opening_width,
                  lip_height + 0.4]);

        // Shallow gasket channel on the underside.
        translate([wall / 2, wall / 2, lid_thickness - gasket_depth])
            difference() {
                rounded_box(
                    [outer_length - wall,
                     outer_width - wall,
                     gasket_depth + 0.1],
                    max(corner_radius - wall / 2, 1)
                );
                translate([gasket_width, gasket_width, -0.1])
                    rounded_box(
                        [outer_length - wall - 2 * gasket_width,
                         outer_width - wall - 2 * gasket_width,
                         gasket_depth + 0.3],
                        max(corner_radius - wall / 2
                            - gasket_width, 0.8)
                    );
            }
    }
}

if (part == "base") {
    base();
} else if (part == "lid") {
    lid();
} else {
    base();
    translate([0, outer_width + 12, 0])
        lid();
}

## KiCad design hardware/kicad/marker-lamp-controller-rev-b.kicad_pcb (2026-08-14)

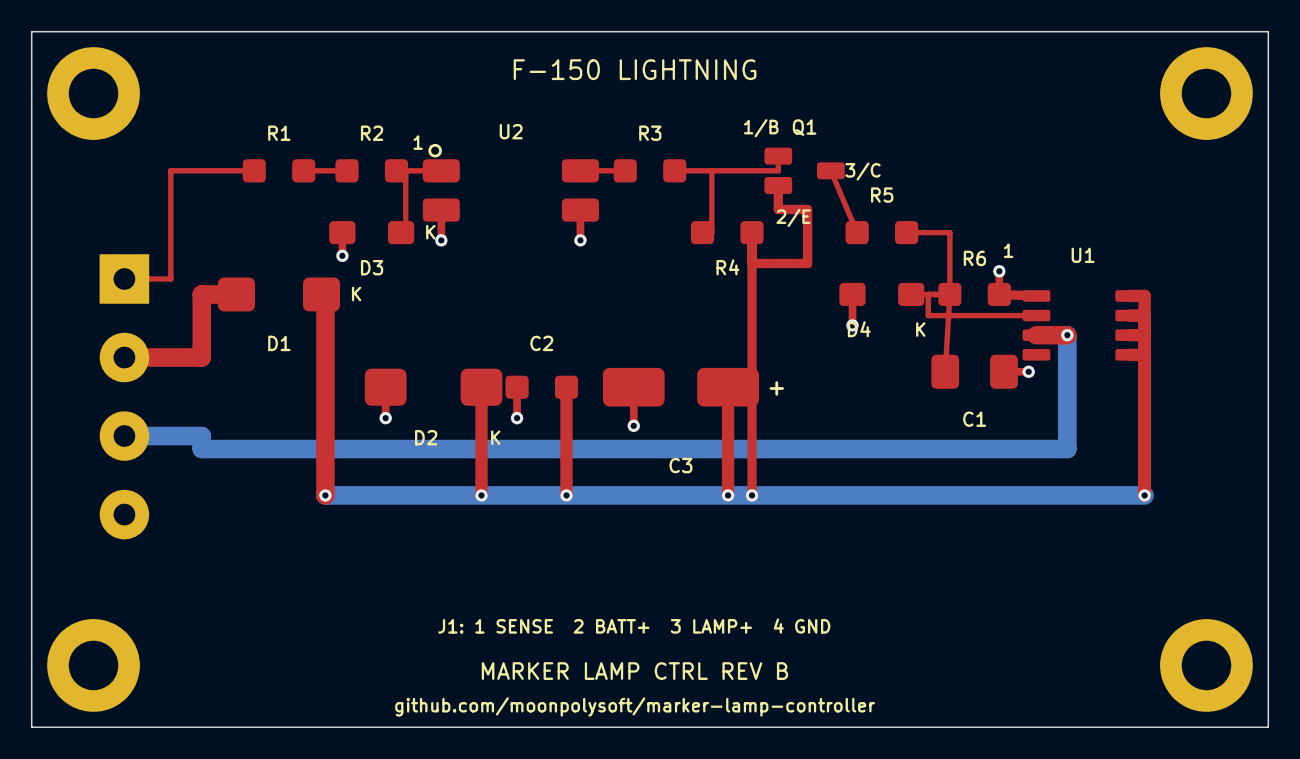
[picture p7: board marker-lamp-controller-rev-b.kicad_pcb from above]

Board: 2 copper layers, 80.0 x 45.0 mm, 21 parts (0 on the bottom side), 11 nets.

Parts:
C1: 10u 25V
C2: 100n 50V
C3: 47u 50V
D1: STPS2H100A
D2: SMBJ22A
D3: 1N4148WS
D4: BZT52C5V1
H1, H2, H3, H4: M3
J1: TBP01R1-508-04BE
Q1: BC807-40
R1, R2: 1k
R3, R5: 10k
R4, R6: 100k
U1: BSP762TXUMA1
U2: VO617A-4X017T

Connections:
CTRL: C1.1, D4.1, R5.2, R6.1, U1.2
GND: C1.2, C2.1, C3.2, D2.2, D3.2, D4.2, J1.4, R6.2, U1.1, U2.2, U2.3
LAMP_OUT: J1.3, U1.3
OPTO_A: D3.1, R2.2, U2.1
OPTO_C: R3.1, U2.4
QBASE: Q1.1, R3.2, R4.1
QCOL: Q1.3, R5.1
SENSE: J1.1, R1.1
SENSE_R1: R1.2, R2.1
VPRE: D1.2, J1.2
VPWR: C2.2, C3.1, D1.1, D2.1, Q1.2, R4.2, U1.5, U1.6, U1.7, U1.8

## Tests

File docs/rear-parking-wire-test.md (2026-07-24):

# Rear Parking-Lamp Wire Field Test

Vehicle: 2023 Ford F-150 Lightning

Purpose: identify a conventional rear parking-lamp voltage that can be used
only as a high-impedance control signal for an auxiliary marker-lamp
controller.

## Test results — initial multimeter measurements

The driver-side candidate passed the functional test: its signaling follows
the desired parking-lamp behavior.

With the parking lamps active, a multimeter measured approximately:

| Vehicle state | Measurement from C4483-10 to body ground |
|---|---:|
| Truck off | 6 V DC indicated |
| Truck on | 8 V DC indicated |

The aftermarket marker-lamp assembly draws 0.25 A while operating from the
truck's energized accessory circuit. This is the relevant normal operating
current at the vehicle's active low-voltage-system voltage.

The 6 V and 8 V readings are likely averaged measurements of a
battery-amplitude PWM waveform used to dim the factory LED lamp. This is an
engineering inference, not yet a confirmed waveform measurement. The revised
controller input is therefore designed to detect and integrate a pulsed input
rather than requiring a steady 12 V level.

## Candidate conductors

Start with the driver-side rear lamp:

| Side | Connector | Cavity | Ford circuit | Wire color | Function |
|---|---|---:|---|---|---|
| Driver/left | C4483, black, 12 cavities | 10 | CLS08 | Violet/green (`VT-GN`) | Park rear left |
| Passenger/right | C4484, black, 12 cavities | 10 | CLS09 | White/orange (`WH-OG`) | Park rear right |

The driver-side violet/green conductor at C4483 cavity 10 is the preferred
first candidate.

## Equipment

- Digital multimeter with insulated probes
- Fine back-probe pin or automotive back-probe adapter
- Plastic trim tool
- Suitable socket/driver for the rear-lamp fasteners
- Optional oscilloscope with an automotive-rated input or appropriately rated
  probe

Do not use an incandescent test lamp. Do not jumper connector cavities.

## Access

1. Park securely, select Park, and switch the vehicle off.
2. Open the tailgate.
3. Remove the fasteners exposed along the inside edge of the driver-side rear
   lamp.
4. Pull the lamp assembly straight rearward to release its locating pins. Do
   not lever against painted panels.
5. Locate the black 12-cavity connector plugged into the lamp assembly.
6. On the truck-harness side, locate the violet wire with a green stripe.
7. Verify the molded cavity number is `10`. Do not identify the conductor by
   counting cavities alone; connector drawings can show different viewing
   faces.

Pins 6 and 12 at this connector are associated with the rear-corner-radar
CAN-FD network. Do not probe them.

## Voltage test

Keep the connector attached so the factory lamp remains operational.

1. Set the multimeter to DC volts, using a range suitable for at least 20 V.
2. Connect the black lead to a verified clean chassis ground.
3. Carefully back-probe C4483 cavity 10 with the red lead. Do not spread or
   damage the terminal.
4. Record the voltage for each state below.

| Vehicle state | Expected result | Measured |
|---|---|---|
| Vehicle asleep, lamps off | Near 0 V | |
| Vehicle awake, lamps off | Near 0 V; brief diagnostic pulses are possible | |
| Parking lamps selected, truck off | PWM suspected; meter indicated about 6 V | 6 V |
| Parking/headlamps selected, truck on | PWM suspected; meter indicated about 8 V | 8 V |
| Brake applied, parking lamps off | Near 0 V | |
| Left turn signal, parking lamps off | Near 0 V | |
| Hazard lamps, parking lamps off | Near 0 V | |
| Reverse selected, parking lamps off | Near 0 V | |
| Unlock/approach lighting | Record whether output activates | |
| Remote start | Record whether output activates | |
| Vehicle charging, otherwise asleep | Record voltage and pulses | |

Use an assistant for control operation. Do not place yourself behind or under
a vehicle that can move. Reverse testing should be performed only with the
vehicle secured and the tester clear of its path.

## Diagnostic-pulse check

A multimeter may average short BCM diagnostic pulses and display a small or
unstable voltage while the lamp is visibly off. If possible, inspect the
conductor with an oscilloscope:

1. Use a common-ground, automotive-safe measurement setup.
2. Observe the line for at least 60 seconds while the lamps are off and the
   vehicle transitions from awake to asleep.
3. Record pulse amplitude, width, and repetition interval.
4. Repeat while charging and shortly after unlocking the vehicle.

Do not connect a grounded bench oscilloscope directly unless its grounding
arrangement is known to be safe for vehicle use.

## Acceptance criteria

The conductor is suitable as a controller input if:

- it remains asserted whenever the desired factory parking lamps are on;
- brake, turn, hazard, and reverse operation do not assert it independently;
- any off-state diagnostic pulses are short enough to reject with input
  filtering; and
- the factory lamp continues to work normally with no warnings or diagnostic
  messages.

The eventual controller input must draw only a few milliamps. The auxiliary
lamps must be powered from a separate fused circuit.

The functional conductor test is complete. An oscilloscope capture remains
useful for finalizing the controller's input threshold and pulse filter, but
is not required before beginning bench prototypes.

## Reference connector records

- C4483 left rear lamp: <https://www.f150lightningforum.com/forum/attachments/rear-lamp-assembly-lh-c4483-pdf.104247/>
- C4484 right rear lamp: <https://www.f150lightningforum.com/forum/attachments/rear-lamp-assembly-rh-c4484-pdf.104245/>

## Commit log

2026-07-24 Document initial marker lamp controller concept
    [controller_enclosure.scad]
2026-07-24 Add fabrication-ready marker lamp controller
    [BOM.csv, controller_enclosure.scad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]
2026-07-25 List mating input connector in BOM
    [BOM.csv]
2026-08-01 Document Revision B PCB corrections
2026-08-01 Prepare printable controller enclosure prototype
    [controller_base_prototype.stl, controller_enclosure.scad, controller_lid_prototype.stl]
2026-08-03 Correct enclosure fit and connector alignment
    [controller_base_prototype.stl, controller_enclosure.scad, controller_lid_prototype.stl]
2026-08-03 Lower enclosure and raise J1 opening sill
    [controller_base_prototype.stl, controller_enclosure.scad, controller_lid_prototype.stl]
2026-08-03 Adjust far-side PCB standoff fit
    [controller_base_prototype.stl, controller_enclosure.scad, controller_lid_prototype.stl]
2026-08-12 Design corrected Revision B controller PCB
    [controller_base_prototype.stl, controller_enclosure.scad, controller_lid_prototype.stl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]
2026-08-13 Prepare project for open-source release
    [controller_base_prototype.stl, controller_enclosure.scad, controller_lid_prototype.stl]
2026-08-14 Add hand-assembly silkscreen markings
    [marker-lamp-controller-rev-b-B_Cu.gbl, marker-lamp-controller-rev-b-B_Mask.gbs, marker-lamp-controller-rev-b-Edge_Cuts.gm1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]
2026-08-14 Replace PCB preview with proper 3D render
